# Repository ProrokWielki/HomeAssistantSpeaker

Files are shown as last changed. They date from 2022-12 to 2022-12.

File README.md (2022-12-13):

## HomeAssistantSpeaker

It is a small, 3D printable rhasspy satellite. It uses INMP441 microphone, MAX98357A audio amplifier paired with 8 Ohm 0.5 W broadband speaker, NeoPixel led strip and ESP32. It is powered from 5V USB.

## What you need

Running [Rhasspy](https://rhasspy.readthedocs.io/en/latest/) instance

To build it you will need:
* 3D printed speaker housing  - [stl file](.Mechanics/HomeAssistentSpeaker.stl)
* PCB - [KiCad Project](./Hardware/)
* 8 Ohm 0.5 W 50 mm broadband speaker
* NeoPixel led strip - Optional
* INMP441
* MAX98357A
* ESP32 - module itself
* LM1117-3.3
* USB connector - 6 pin
* a few passive components - resistors and capacitors

And most important **Soldering skills**

## Assambly

* Solder everything together
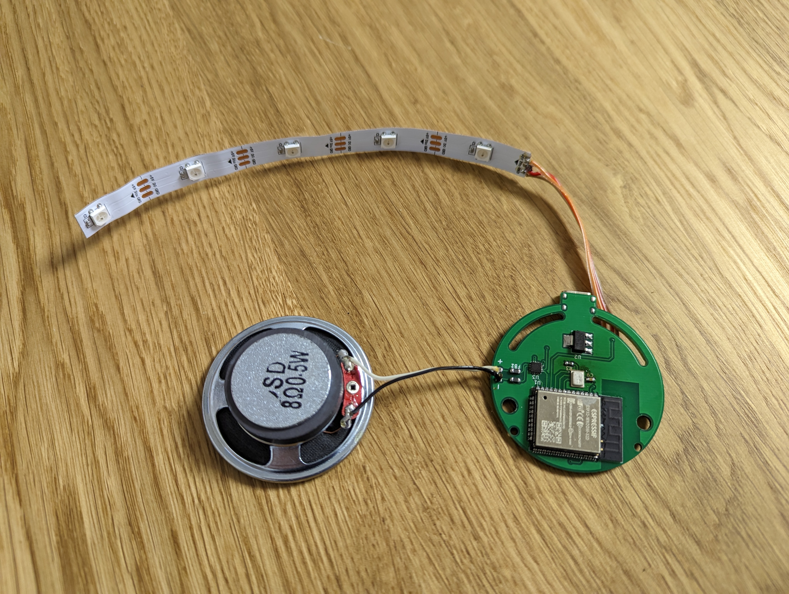
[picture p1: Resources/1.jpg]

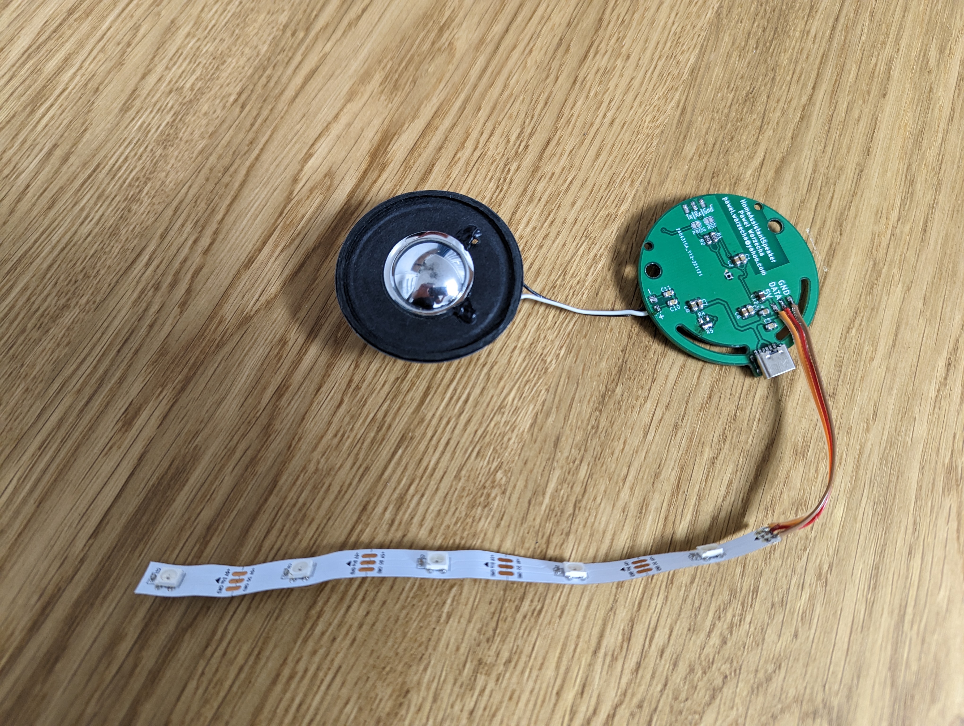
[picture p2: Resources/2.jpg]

* Put it inside the shell (order from the bottom: speaker, board, led strip)
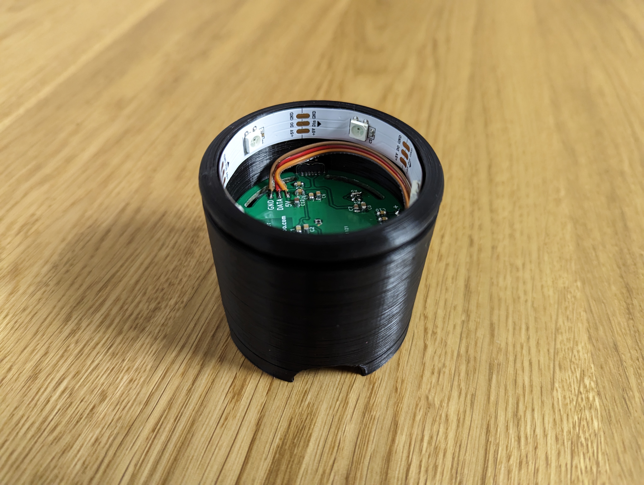
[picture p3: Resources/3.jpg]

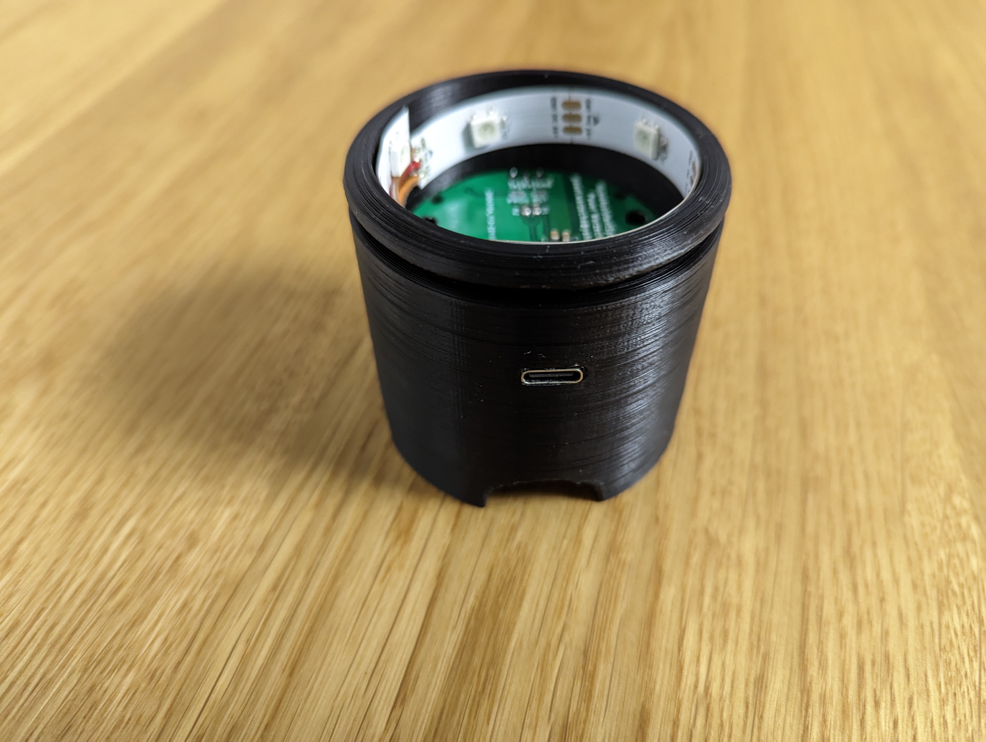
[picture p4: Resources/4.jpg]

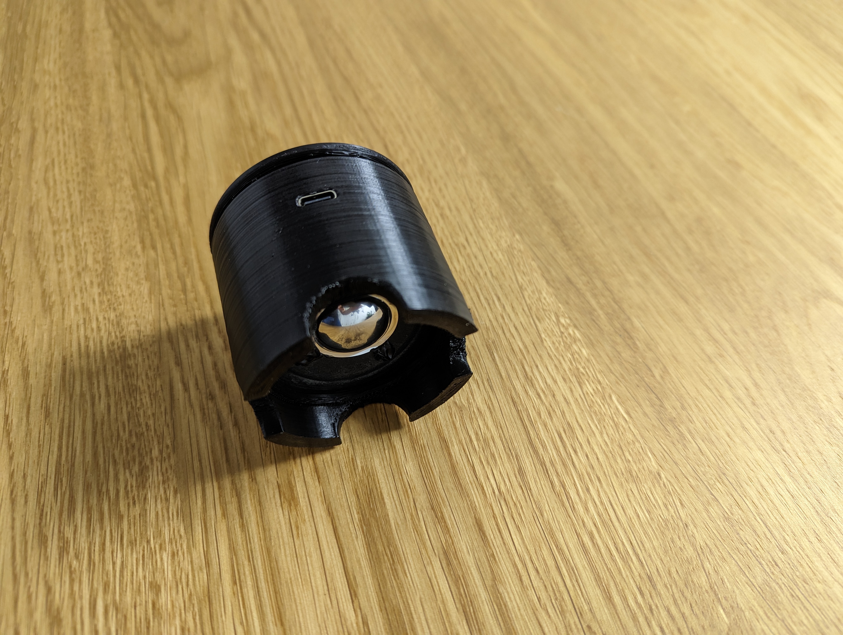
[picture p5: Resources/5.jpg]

* Add speaker mesh fabric
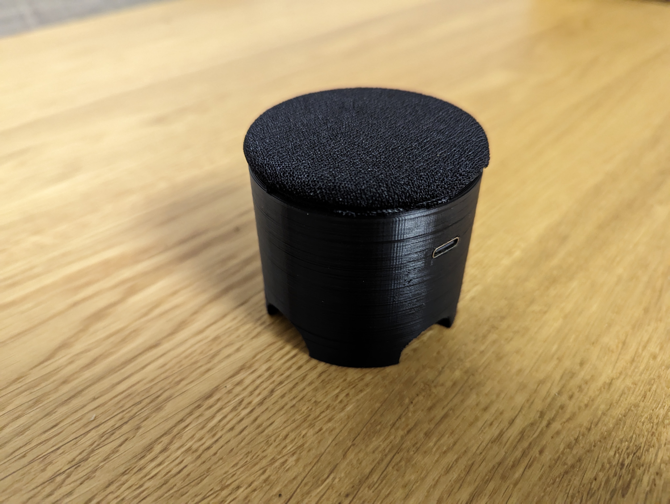
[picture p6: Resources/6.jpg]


## Demo
IMAGE ALT TEXT HERE (https://www.youtube.com/watch?v=3Iw6qICICjs)

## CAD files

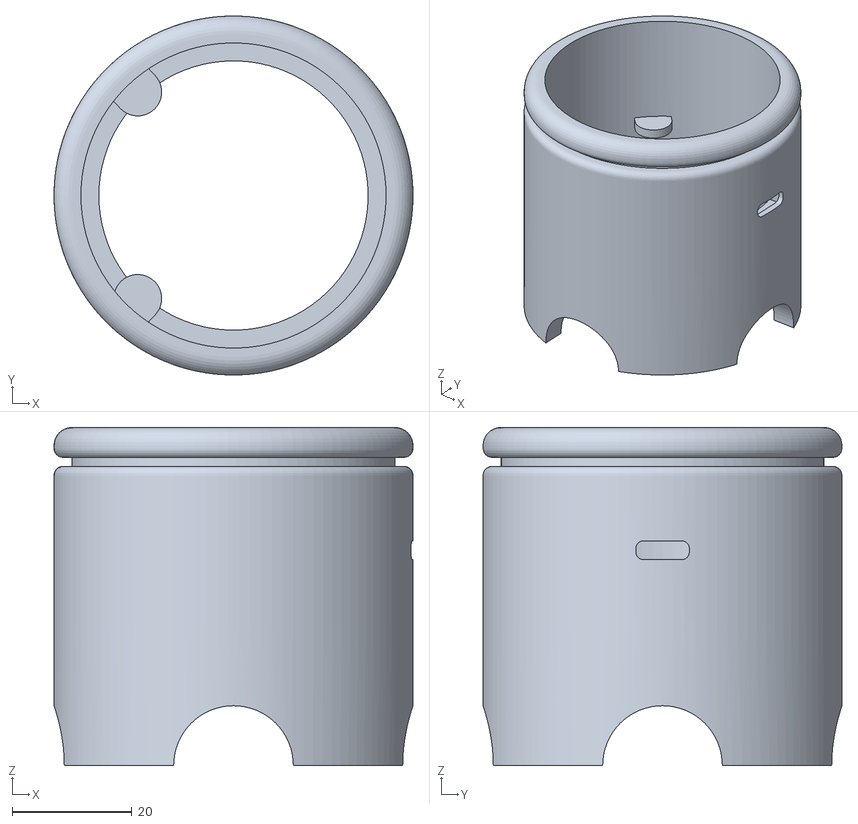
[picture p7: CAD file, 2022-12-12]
Mechanics/HomeAssistentSpeaker.stl
60.0 x 60.0 x 56.5

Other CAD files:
Mechanics/HomeAssistentSpeaker.f3d

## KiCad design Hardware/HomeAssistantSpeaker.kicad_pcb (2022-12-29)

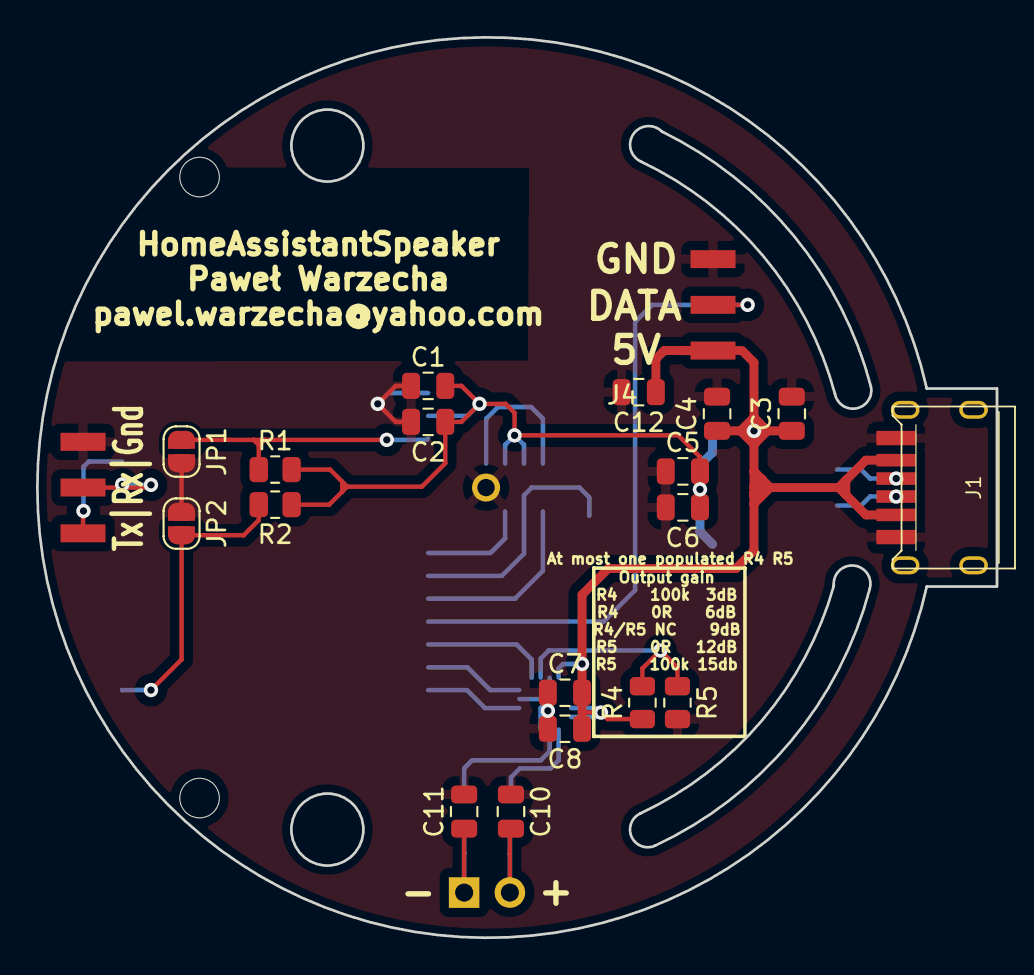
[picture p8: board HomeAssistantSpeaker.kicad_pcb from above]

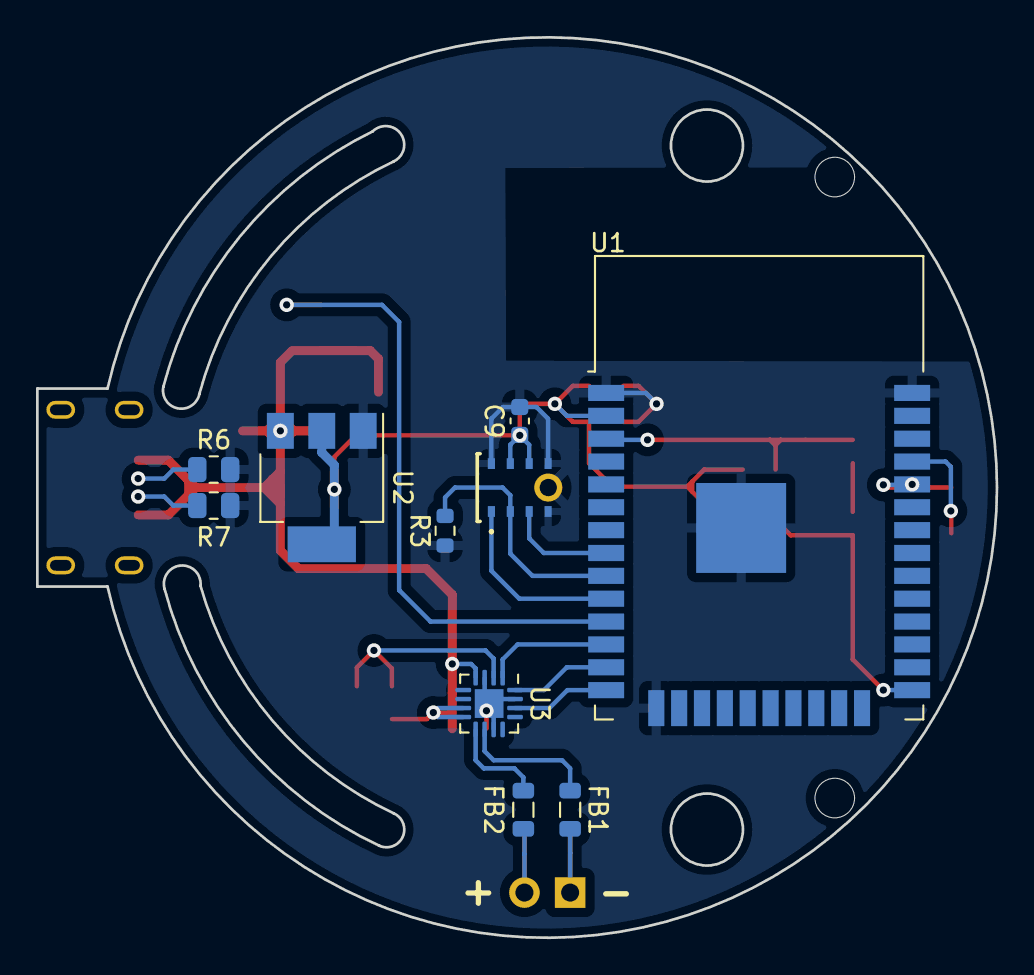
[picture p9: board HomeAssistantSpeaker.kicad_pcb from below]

Board: 2 copper layers, 53.3 x 50.0 mm, 31 parts (10 on the bottom side), 21 nets.

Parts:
C1, C3, C5, C7: 100n; C_0805_2012Metric
C2, C4, C6, C8: 10u; C_0805_2012Metric
C9: 100n; C_0603_1608Metric
C10, C11: 220p; C_0805_2012Metric
C12: 1u; C_0805_2012Metric
FB1, FB2: 20uH; L_0805_2012Metric
J1: USB_C_Receptacle_USB2.0; TYPE-C-31-M-17_handsolder
J2: Speaker; PinHeader_1x02_P2.54mm_Vertical
J3: Prog; Harwin_M20-89003xx_1x03_P2.54mm_Horizontal
J4: LED; Harwin_M20-89003xx_1x03_P2.54mm_Horizontal
JP1: Reset; SolderJumper-2_P1.3mm_Open_RoundedPad1.0x1.5mm
JP2: Program; SolderJumper-2_P1.3mm_Open_RoundedPad1.0x1.5mm
MK1: INMP441ACEZ
R1, R2, R4, R5: 10k; R_0805_2012Metric
R3: 100k; R_0603_1608Metric
R6, R7: 5k1; R_0805_2012Metric
U1: ESP32-WROOM-32
U2: LM1117-3.3; SOT-223-3_TabPin2
U3: MAX98357AETE+; TQFN-16-1EP_3x3mm_P0.5mm_EP1.6x1.6mm

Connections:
+3V3: C1.1, C2.1, C5.1, C6.1, C9.1, MK1.7 (VDD), MK1.8 (CHIPEN), R1.1, R2.1, U1.2 (VDD), U2.2 (VO)
+5V: C3.1, C4.1, C7.1, C8.1, C12.1, J1.A9 (VBUS), J1.B9 (VBUS), J4.1, R4.1, U2.3 (VI), U3.4 (~SD_MODE), U3.7 (VDD), U3.8 (VDD)
GND: C1.2, C2.2, C3.2, C4.2, C5.2, C6.2, C7.2, C8.2, C9.2, C10.2, C11.2, C12.2, J1.A12 (GND), J1.B12 (GND), J3.3, J4.3, JP1.1, JP2.2, MK1.4 (L/R), MK1.5 (GND_1), MK1.6 (GND_2), MK1.9 (GND_3), R3.2, R5.1, R6.2, R7.2, U1.1 (GND), U1.15 (GND), U1.38 (GND), U1.39 (GND), U2.1 (GND), U3.3 (GND), U3.11 (GND), U3.15 (GND), U3.17 (EP)
Gain: R4.2, R5.2, U3.2 (GAIN_SLOT)
LED_DATA: J4.2, U1.11 (IO26)
Mic_SCK: MK1.1 (SCK), U1.10 (IO25)
Mic_SD: MK1.2 (SD), R3.1, U1.9 (IO33)
Mic_WS: MK1.3 (WS), U1.8 (IO32)
unnamed: C10.1, FB2.1, J2.2
unnamed: C11.1, FB1.1, J2.1
unnamed: FB1.2, U3.10 (OUTN)
unnamed: FB2.2, U3.9 (OUTP)
unnamed: J1.A5 (CC1), R7.1
unnamed: J1.B5 (CC2), R6.1
unnamed: JP1.2, R1.2, U1.3 (EN)
unnamed: JP2.1, R2.2, U1.25 (IO0)
Rx: J3.2, U1.34 (RXD0/IO3)
Speaker_bclk: U1.13 (IO14), U3.16 (BCLK)
Speaker_din: U1.12 (IO27), U3.1 (DIN)
Speaker_lrclk: U1.14 (IO12), U3.14 (LRCLK)
Tx: J3.1, U1.35 (TXD0/IO1)

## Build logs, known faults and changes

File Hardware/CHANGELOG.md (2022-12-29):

# Chenglog

### Rev. B - 20.12.2022
* Added missing resitiors for usb c power

### Rev. A - 20.11.2022
* Initial design

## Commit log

2022-11-20 Inital design of the PCB
    [HomeAssistantSpeaker.kicad_pcb, HomeAssistantSpeaker.sch]
2022-12-10 Silkscreen cleanup
    * Moved overlaping silkscreen values
    * Added gain setting info on the PCB
    [HomeAssistantSpeaker.kicad_pcb]
2022-12-12 Converted to KiCad 6
    [HomeAssistantSpeaker.kicad_sch, HomeAssistantSpeaker.sch]
2022-12-12 Added STL and fusion360 files for speaker housing
    [HomeAssistentSpeaker.f3d, HomeAssistentSpeaker.stl]
2022-12-29 Rev B:
    * Added missing resitiors for usb c power
    [HomeAssistantSpeaker.kicad_pcb, HomeAssistantSpeaker.kicad_sch]
